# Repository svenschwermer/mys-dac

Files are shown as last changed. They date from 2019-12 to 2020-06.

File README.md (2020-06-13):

# Audio DAC around the MYS-6ULX-IOT

## UART
Connection diagram for JP1 with a FTDI TTL-232R cable:
1. TX – yellow
1. RX – orange
1. GND – black

## Host PC setup
NetworkManager:
```
nmcli con add \
    type ethernet
    ifname eno1 \
    con-name ethernet-static \
    ipv4.method manual \
    ipv4.addresses 192.168.100.1/24 \
    ipv6.method ignore
```

`/etc/dnsmasq.conf`
```
port=0
interface=eno1
dhcp-range=192.168.100.10,192.168.100.100,12h
enable-tftp
tftp-root=/srv/tftp
```

`/etc/nfs.conf`
```ini
[nfsd]
udp=y
vers2=y
```

`/etc/exports`
```
/srv/nfs/mys_rfs *(rw,no_root_squash,no_subtree_check)
```

## Unmute output
```sh
amixer sset 'Output Mixer HiFi' on
```

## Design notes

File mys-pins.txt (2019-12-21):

ECSPI1
MISO: CSI_DATA07 LCD_DATA23
MOSI: CSI_DATA06 LCD_DATA22
RDY: LCD_DATA12
SCLK: CSI_DATA04 LCD_DATA20
SS0: CSI_DATA05 LCD_DATA21
SS1: LCD_DATA05
SS2: LCD_DATA06
SS3: LCD_DATA07

ECSPI2
MISO: CSI_DATA03 UART5_RX_DATA
MOSI: CSI_DATA02 UART5_TX_DATA
RDY: LCD_ENABLE
SCLK: CSI_DATA00 UART4_TX_DATA
SS0: CSI_DATA01 UART4_RX_DATA
SS1: LCD_HSYNC
SS2: LCD_VSYNC
SS3: LCD_RESET

ECSPI3
MISO: NAND_CLE UART2_RTS_B
MOSI: NAND_CE1_B UART2_CTS_B
RDY: NAND_WP_B
SCLK: NAND_CE0_B UART2_RX_DATA
SS0: NAND_READY_B UART2_TX_DATA
SS1: NAND_ALE
SS2: NAND_RE_B
SS3: NAND_WE_B

ECSPI4
MISO: ENET2_TX_CLK NAND_DATA06
MOSI: ENET2_TX_EN NAND_DATA05
RDY: NAND_DATA00
SCLK: ENET2_TX_DATA1 NAND_DATA04
SS0: ENET2_RX_ER NAND_DATA07
SS1: NAND_DATA01
SS2: NAND_DATA02
SS3: NAND_DATA03

I2C1
SCL: CSI_PIXCLK GPIO1_IO02 UART4_TX_DATA
SDA: CSI_MCLK GPIO1_IO03 UART4_RX_DATA

I2C2
SCL: CSI_HSYNC GPIO1_IO00 UART5_TX_DATA
SDA: CSI_VSYNC GPIO1_IO01 UART5_RX_DATA

I2C3
SCL: ENET2_RX_DATA0 LCD_DATA01 UART1_TX_DATA
SDA: ENET2_RX_DATA1 LCD_DATA00 UART1_RX_DATA

I2C4
SCL: ENET2_RX_EN LCD_DATA03 UART2_TX_DATA
SDA: ENET2_TX_DATA0 LCD_DATA02 UART2_RX_DATA

SAI1:
MCLK: CSI_DATA01 LCD_DATA00
RX_BCLK: CSI_DATA03
RX_DATA: CSI_DATA06 LCD_DATA03
RX_SYNC: CSI_DATA02
TX_BCLK: CSI_DATA05 LCD_DATA02
TX_DATA: CSI_DATA07 LCD_DATA04
TX_SYNC: CSI_DATA04 LCD_DATA01

SAI2
MCLK: JTAG_TMS SD1_CLK
RX_BCLK: NAND_DATA06
RX_DATA: JTAG_TCK SD1_DATA2
RX_SYNC: SD1_CMD
TX_BCLK: JTAG_TDI SD1_DATA1
TX_DATA: JTAG_TRST_B SD1_DATA3
TX_SYNC: JTAG_TDO SD1_DATA0

SAI3
MCLK: LCD_CLK LCD_DATA09
RX_BCLK: LCD_DATA11
RX_DATA: LCD_DATA14
RX_SYNC: LCD_VSYNC LCD_DATA10
TX_BCLK: LCD_DATA13 LCD_HSYNC
TX_DATA: LCD_DATA15 LCD_RESET
TX_SYNC: LCD_DATA12 LCD_ENABLE

SPDIF
EXT_CLK: LCD_DATA07 NAND_DQS
IN: GPIO1_IO09 LCD_DATA08 SD1_CLK UART1_RX_DATA
LOCK: LCD_DATA06
OUT: GPIO1_IO08 JTAG_MOD LCD_DATA05 SD1_CMD UART1_TX_DATA
SR_CLK: LCD_DATA04

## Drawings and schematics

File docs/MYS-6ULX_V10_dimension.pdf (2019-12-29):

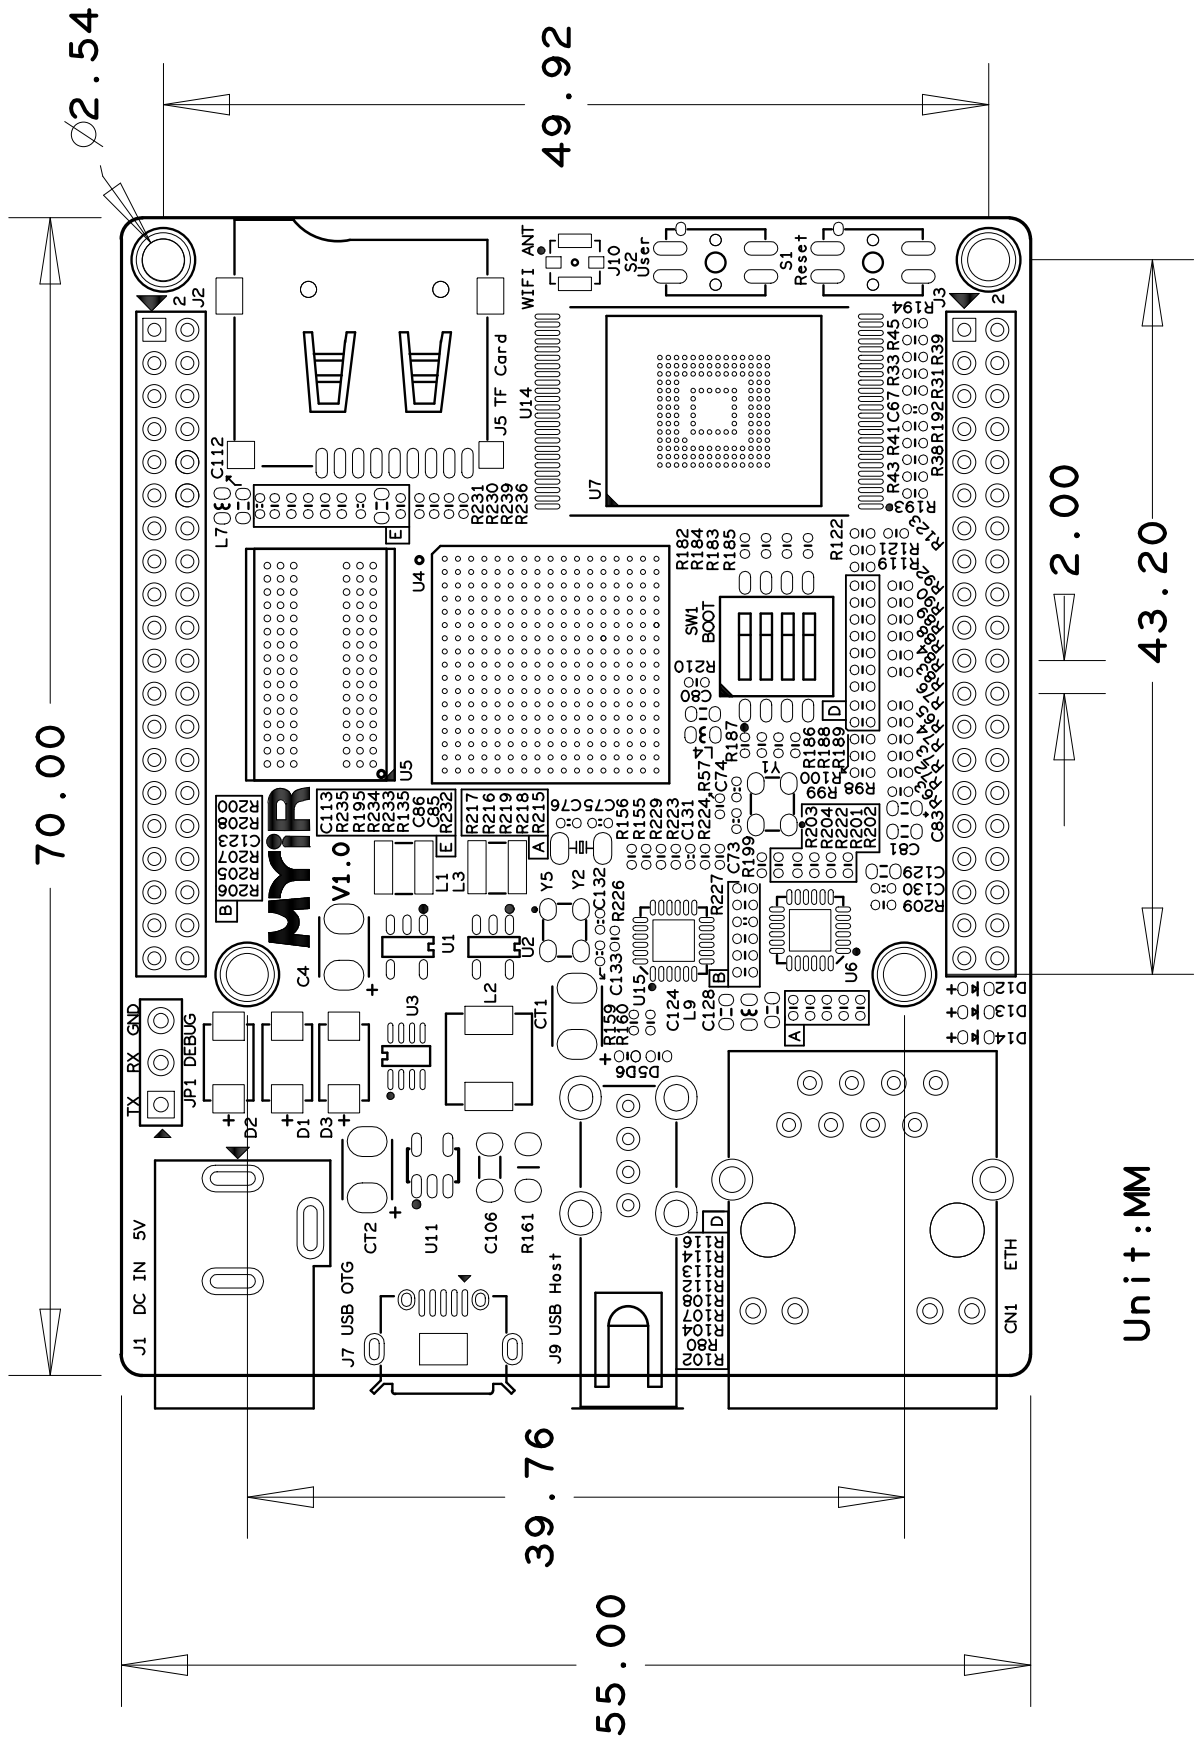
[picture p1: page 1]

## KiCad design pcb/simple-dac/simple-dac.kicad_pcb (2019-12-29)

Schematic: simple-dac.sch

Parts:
C1, C2, C3, C4, C12, C13, C14: 10µ; C_0805_2012Metric_Pad1.15x1.40mm_HandSolder
C5, C6, C9, C10, C11: 100n; C_0805_2012Metric_Pad1.15x1.40mm_HandSolder
C7, C8: 18p; C_0805_2012Metric_Pad1.15x1.40mm_HandSolder
C15, C16: 220µ; CP_Radial_D6.3mm_P2.50mm; Voltage 10V
H1, H2: MountingHole_Pad; KEYSTONE_7790
J1: Conn_02x07_Odd_Even; TE_MICRO-MATCH_FOB.14P
J2: AudioJack4; SJ-4351X-SMT
R1, R7, R8: 47k; R_0805_2012Metric_Pad1.15x1.40mm_HandSolder
R2, R5, R6: 0; R_0805_2012Metric_Pad1.15x1.40mm_HandSolder
R3: 680; R_0805_2012Metric_Pad1.15x1.40mm_HandSolder
R4: 40k; R_0805_2012Metric_Pad1.15x1.40mm_HandSolder
U1: WM8731; SSOP-28_5.3x10.2mm_P0.65mm
Y1: 11.2896MHz; Crystal_HC49-4H_Vertical

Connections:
+3V3: C2.1, C3.2, C5.1, C6.2, C9.1, C10.1, C12.1, C13.1, J1.2, U1.1, U1.8, U1.14, U1.27
BCLK: J1.8, U1.3
DIN: J1.5, U1.4
DOUT: J1.11, U1.6
GND: C1.1, C2.2, C3.1, C5.2, C6.1, C7.2, C8.2, C9.2, C10.2, C11.2, C12.2, C13.2, C14.2, J1.1, J2.S, R1.2, R7.2, R8.2, U1.11, U1.15, U1.21, U1.22, U1.28
LRCLK: J1.6, R2.2, U1.5
MCLK: J1.10, R6.2
MIC: C1.2, C4.1, J2.R2, R1.1, R3.1
unnamed: C4.2, R4.1
unnamed: C7.1, U1.26, Y1.1
unnamed: C8.1, R5.2, Y1.2
unnamed: C11.1, C14.1, U1.16
unnamed: C15.1, U1.9
unnamed: C15.2, J2.T, R8.1
unnamed: C16.1, U1.10
unnamed: C16.2, J2.R1, R7.1
unnamed: R2.1, U1.7
unnamed: R3.2, U1.17
unnamed: R4.2, U1.18
unnamed: R5.1, R6.1, U1.25
SCL: J1.4, U1.24
SDA: J1.3, U1.23

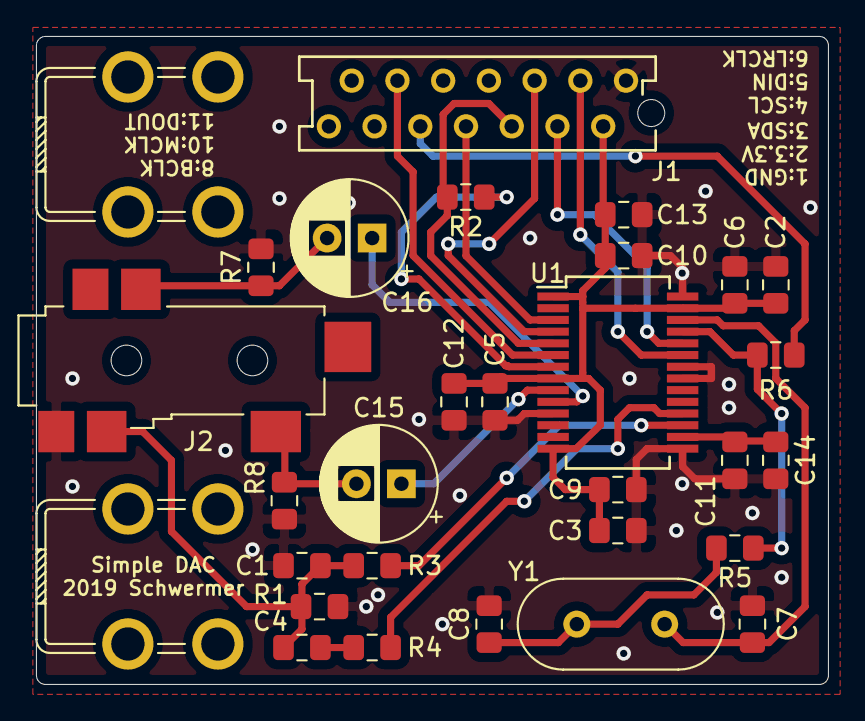
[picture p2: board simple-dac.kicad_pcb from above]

Board: 2 copper layers, 44.0 x 36.0 mm, 30 parts (0 on the bottom side), 22 nets.

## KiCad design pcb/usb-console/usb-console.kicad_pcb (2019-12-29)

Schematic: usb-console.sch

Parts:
C1: 10µ; C_0805_2012Metric_Pad1.15x1.40mm_HandSolder
C2, C3: 100n; C_0805_2012Metric_Pad1.15x1.40mm_HandSolder
D1: RED; LED_D3.0mm_Horizontal_O1.27mm_Z2.0mm
D2: GREEN; LED_D3.0mm_Horizontal_O3.81mm_Z6.0mm
H1, H2: MountingHole; KEYSTONE_7790
J1: USB_B_Mini; HIROSE_MX60-MB-5S8
J2: Conn_02x02_Odd_Even; TE_MICRO-MATCH_FOB.04P
R1, R2: R; R_0805_2012Metric_Pad1.15x1.40mm_HandSolder
U1: CH340E; MSOP-10_3x3mm_P0.5mm

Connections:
+5V: C1.1, C2.1, J1.1, J2.1, R2.2, U1.7
/D+: J1.3, U1.1
/D-: J1.2, U1.2
GND: C1.2, C2.2, C3.2, D1.1, D2.1, J1.5, J1.6, J2.4, U1.3
unnamed: C3.1, U1.10
unnamed: D1.2, R1.2
unnamed: D2.2, R2.1
unnamed: J2.2, U1.9
unnamed: J2.3, U1.8
unnamed: R1.1, U1.6

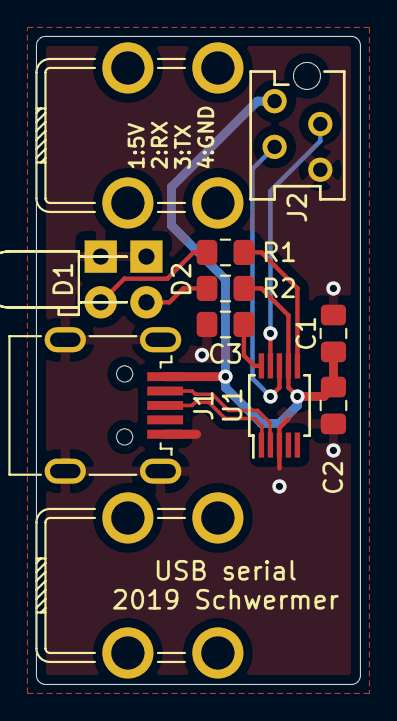
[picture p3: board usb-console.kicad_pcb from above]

Board: 2 copper layers, 18.0 x 36.0 mm, 12 parts (0 on the bottom side), 10 nets.

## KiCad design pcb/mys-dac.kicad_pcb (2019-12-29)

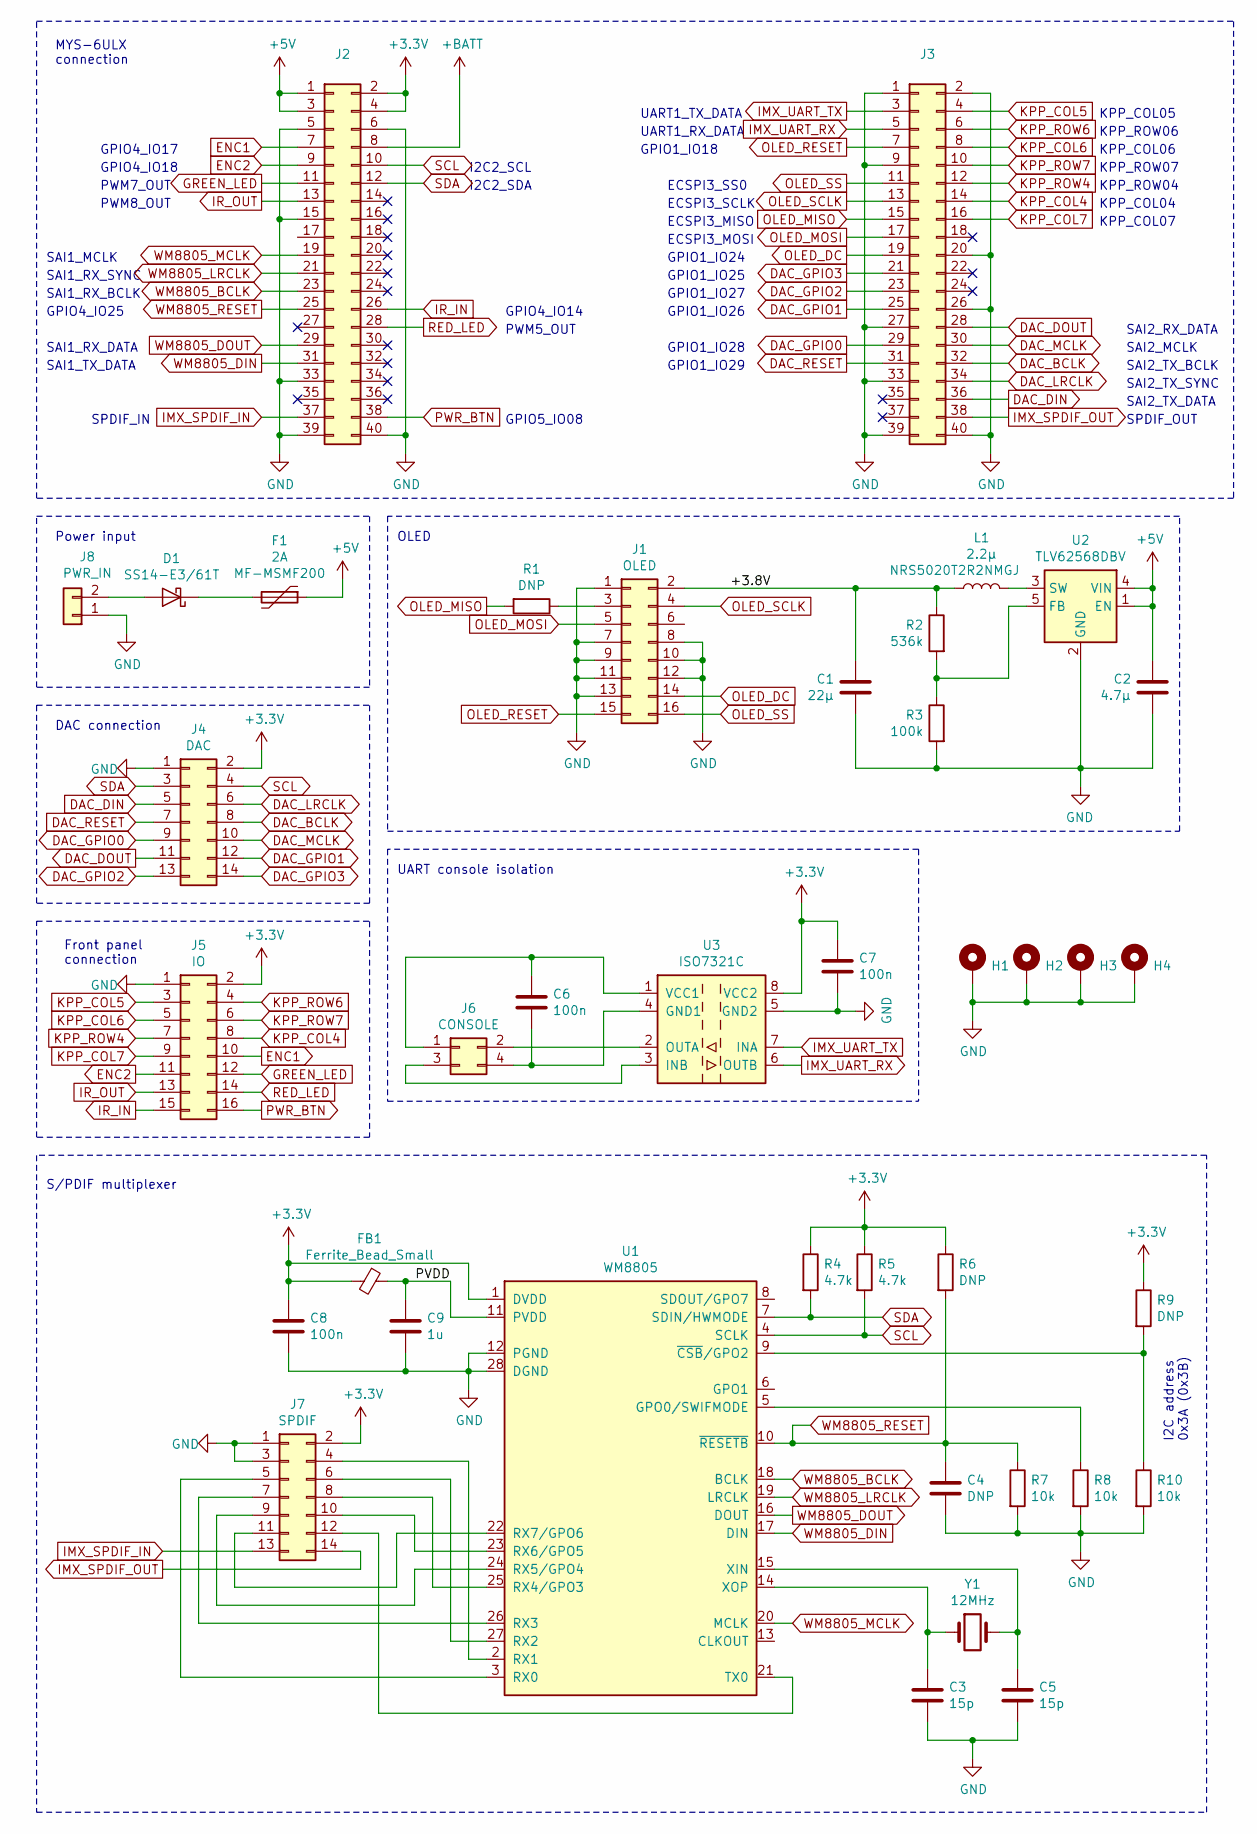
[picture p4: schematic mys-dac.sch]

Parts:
C1: 22µ; C_1206_3216Metric_Pad1.42x1.75mm_HandSolder
C2: 4.7µ; C_1206_3216Metric_Pad1.42x1.75mm_HandSolder
C3, C5: 15p; C_0805_2012Metric_Pad1.15x1.40mm_HandSolder
C4: C; C_0805_2012Metric_Pad1.15x1.40mm_HandSolder
C6, C7, C8: 100n; C_0805_2012Metric_Pad1.15x1.40mm_HandSolder
C9: 1u; C_0805_2012Metric_Pad1.15x1.40mm_HandSolder
D1: SS14-E3/61T; D_SMA_Handsoldering
F1: 2A; Fuse_1812_4532Metric_Pad1.30x3.40mm_HandSolder; Part MF-MSMF200
FB1: Ferrite_Bead_Small; L_0805_2012Metric_Pad1.15x1.40mm_HandSolder
H1, H2, H3, H4: MountingHole_Pad; MountingHole_2.5mm_Pad
J1: OLED; TE_MICRO-MATCH_FOB.16P
J2, J3: Conn_02x20_Odd_Even; PinSocket_2x20_P2.00mm_Vertical
J4: DAC; TE_MICRO-MATCH_FOB.14P
J5: IO; TE_MICRO-MATCH_FOB.16P
J6: CONSOLE; TE_MICRO-MATCH_FOB.04P
J7: SPDIF; TE_MICRO-MATCH_FOB.14P
J8: PWR_IN; JST_XH_B2B-XH-A_1x02_P2.50mm_Vertical
L1: 2.2µ; L_Taiyo-Yuden_NR-50xx_HandSoldering; Part NRS5020T2R2NMGJ
R1, R6, R9: R; R_0805_2012Metric_Pad1.15x1.40mm_HandSolder
R2: 536k; R_0805_2012Metric_Pad1.15x1.40mm_HandSolder
R3: 100k; R_0805_2012Metric_Pad1.15x1.40mm_HandSolder
R4, R5: 4.7k; R_0805_2012Metric_Pad1.15x1.40mm_HandSolder
R7, R8, R10: 10k; R_0805_2012Metric_Pad1.15x1.40mm_HandSolder
U1: WM8805; SSOP-28_5.3x10.2mm_P0.65mm
U2: TLV62568DBV; SOT-23-5
U3: ISO7321C; SOIC-8_3.9x4.9mm_P1.27mm
Y1: 12MHz; Crystal_HC49-4H_Vertical

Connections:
+3V3: C7.1, C8.1, FB1.2, J2.2, J2.4, J4.2, J5.2, J7.2, R4.1, R5.1, R6.1, R9.1, U1.1 (DVDD), U3.8 (VCC2)
+5V: C2.1, F1.1, J2.1, J2.3, U2.1 (EN), U2.4 (VIN)
+BATT: J2.8
/+3.8V: C1.1, J1.2, L1.2, R2.1
/PVDD: C9.1, FB1.1, U1.11 (PVDD)
DAC_BCLK: J3.32, J4.8
DAC_DIN: J3.36, J4.5
DAC_DOUT: J3.28, J4.11
DAC_GPIO0: J3.29, J4.9
DAC_GPIO1: J3.25, J4.12
DAC_GPIO2: J3.23, J4.13
DAC_GPIO3: J3.21, J4.14
DAC_LRCLK: J3.34, J4.6
DAC_MCLK: J3.30, J4.10
DAC_RESET: J3.31, J4.7
ENC1: J2.7, J5.10
ENC2: J2.9, J5.11
GND: C1.2, C2.2, C3.2, C4.2, C5.2, C7.2, C8.2, C9.2, H1.1, H2.1, H3.1, H4.1, J1.1, J1.7, J1.8, J1.9, J1.10, J1.11, J1.12, J1.13, J2.5, J2.6, J2.15, J2.33, J2.39, J2.40, J3.1, J3.2, J3.9, J3.20, J3.26, J3.27, J3.33, J3.39, J3.40, J4.1, J5.1, J7.1, J7.3, J8.1, R3.2, R7.2, R8.2, R10.2, U1.12 (PGND), U1.28 (DGND), U2.2 (GND), U3.5 (GND2)
GREEN_LED: J2.11, J5.12
IMX_SPDIF_IN: J2.37, J7.13
IMX_SPDIF_OUT: J3.38, J7.14
IMX_UART_RX: J3.5, U3.6 (OUTB)
IMX_UART_TX: J3.3, U3.7 (INA)
IR_IN: J2.26, J5.15
IR_OUT: J2.13, J5.13
KPP_COL4: J3.14, J5.8
KPP_COL5: J3.4, J5.3
KPP_COL6: J3.8, J5.5
KPP_COL7: J3.16, J5.9
KPP_ROW4: J3.12, J5.7
KPP_ROW6: J3.6, J5.4
KPP_ROW7: J3.10, J5.6
unnamed: C3.1, U1.14 (XOP), Y1.1
unnamed: C5.1, U1.15 (XIN), Y1.2
unnamed: C6.1, J6.1, U3.1 (VCC1)
unnamed: C6.2, J6.4, U3.4 (GND1)
unnamed: D1.1 (K), F1.2
unnamed: D1.2 (A), J8.2
unnamed: J1.3, R1.1
unnamed: J6.2, U3.2 (OUTA)
unnamed: J6.3, U3.3 (INB)
unnamed: J7.4, U1.2 (RX1)
unnamed: J7.5, U1.3 (RX0)
unnamed: J7.6, U1.27 (RX2)
unnamed: J7.7, U1.26 (RX3)
unnamed: J7.8, U1.25 (RX4/GPO3)
unnamed: J7.9, U1.24 (RX5/GPO4)
unnamed: J7.10, U1.23 (RX6/GPO5)
unnamed: J7.11, U1.22 (RX7/GPO6)
unnamed: J7.12, U1.21 (TX0)
unnamed: L1.1, U2.3 (SW)
unnamed: R2.2, R3.1, U2.5 (FB)
unnamed: R8.1, U1.5 (GPO0/SWIFMODE)
unnamed: R9.2, R10.1, U1.9 (~CSB~/GPO2)
OLED_DC: J1.14, J3.19
OLED_MISO: J3.15, R1.2
OLED_MOSI: J1.5, J3.17
OLED_RESET: J1.15, J3.7
OLED_SCLK: J1.4, J3.13
OLED_SS: J1.16, J3.11
PWR_BTN: J2.38, J5.16
RED_LED: J2.28, J5.14
SCL: J2.10, J4.4, R5.2, U1.4 (SCLK)
SDA: J2.12, J4.3, R4.2, U1.7 (SDIN/HWMODE)
WM8805_BCLK: J2.23, U1.18 (BCLK)
WM8805_DIN: J2.31, U1.17 (DIN)
WM8805_DOUT: J2.29, U1.16 (DOUT)
WM8805_LRCLK: J2.21, U1.19 (LRCLK)
WM8805_MCLK: J2.19, U1.20 (MCLK)
WM8805_RESET: C4.1, J2.25, R6.2, R7.1, U1.10 (~RESETB)

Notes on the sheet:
I2C address 0x3A (0x3B)
UART console isolation
OLED
MYS-6ULX connection
PWM7_OUT
SAI1_MCLK
GPIO4_IO18
GPIO4_IO17
PWM8_OUT
SAI1_RX_SYNC
SAI1_RX_BCLK
GPIO4_IO25
SAI1_RX_DATA
SAI1_TX_DATA
SPDIF_IN
I2C2_SCL
GPIO4_IO14
PWM5_OUT
GPIO5_IO08
UART1_TX_DATA
UART1_RX_DATA
GPIO1_IO18
ECSPI3_SS0
ECSPI3_SCLK
ECSPI3_MISO
ECSPI3_MOSI
GPIO1_IO24
GPIO1_IO25
GPIO1_IO27
GPIO1_IO26
GPIO1_IO28
GPIO1_IO29
KPP_COL05
KPP_ROW06
KPP_COL06
KPP_ROW07
KPP_ROW04
KPP_COL04
KPP_COL07
SAI2_RX_DATA

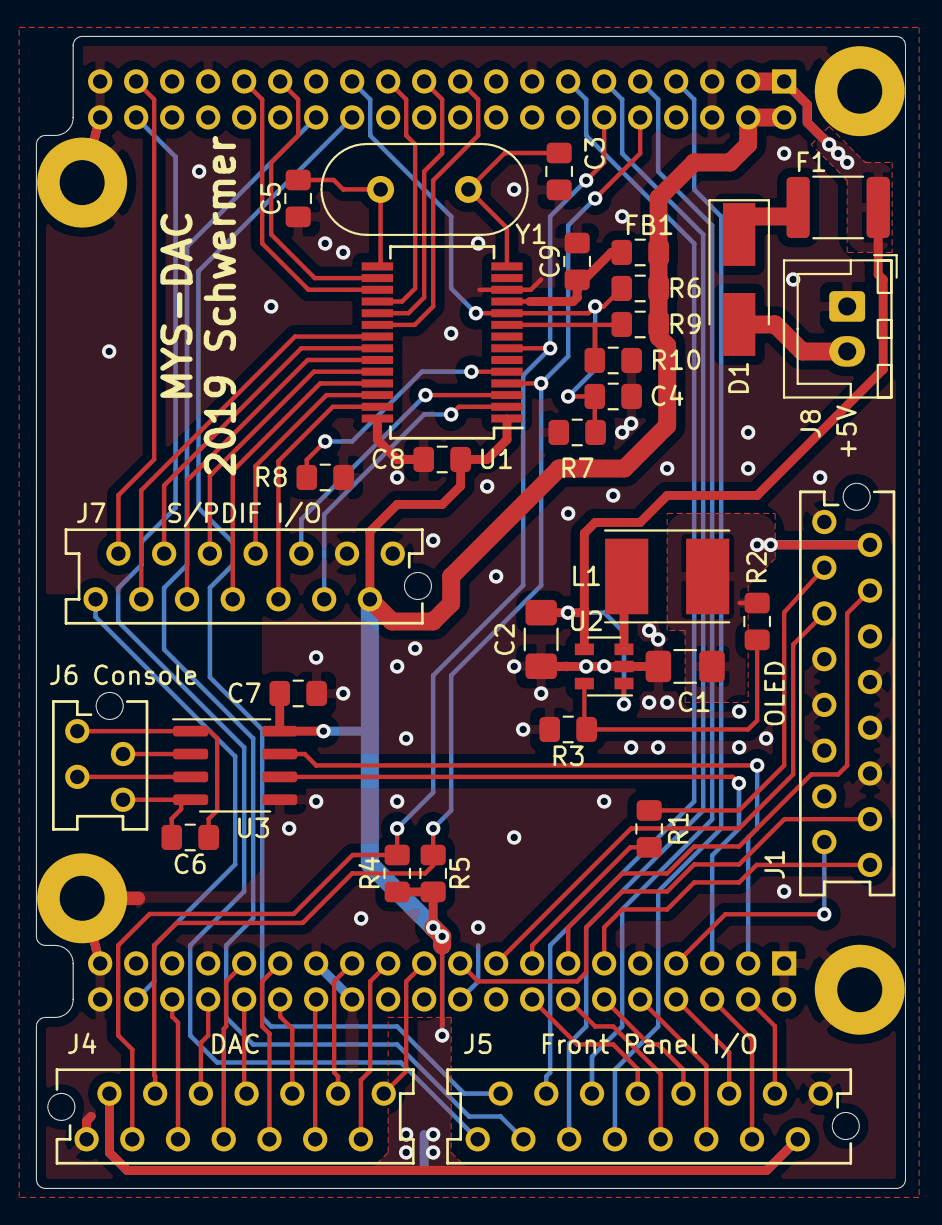
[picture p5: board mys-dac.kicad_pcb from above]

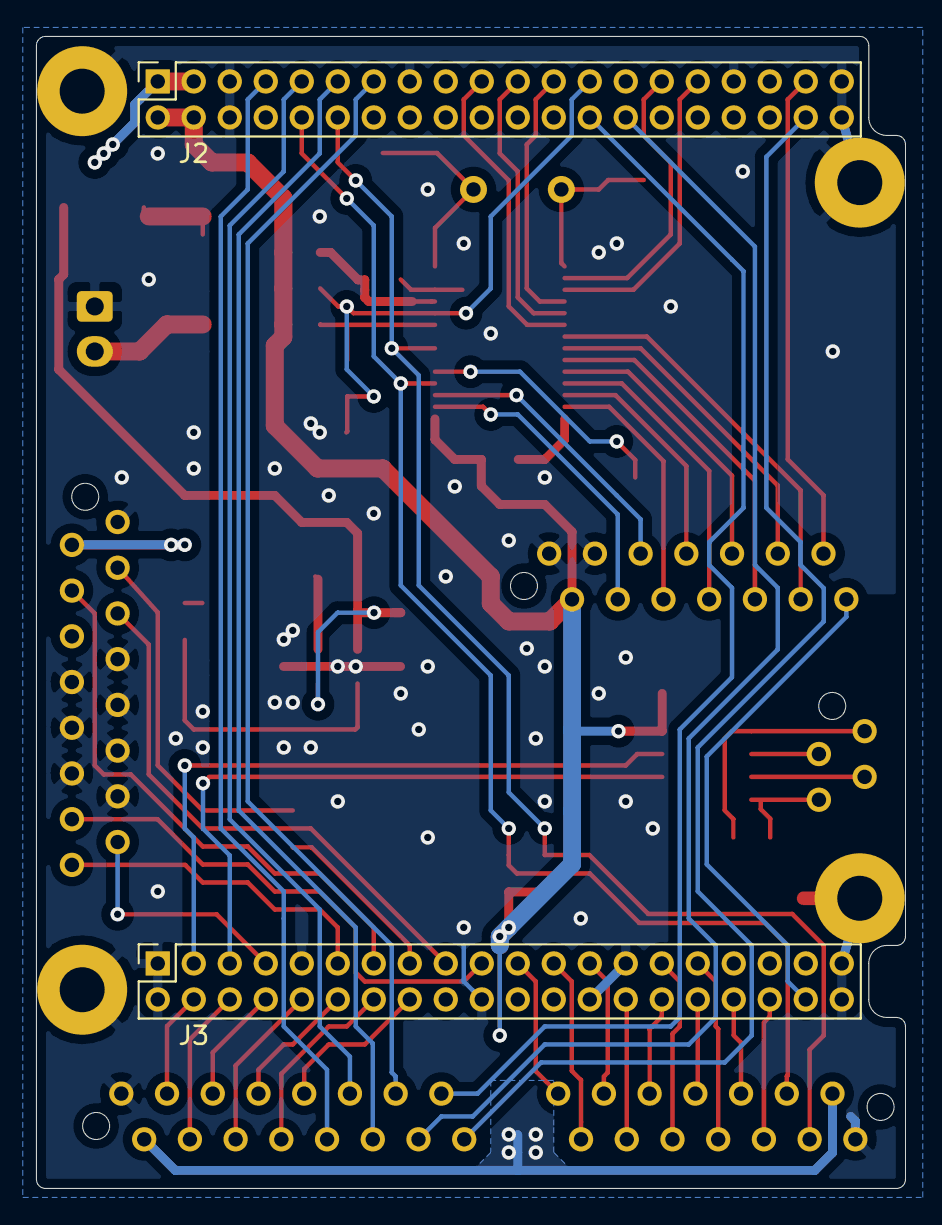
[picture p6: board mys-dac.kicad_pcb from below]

Board: 2 copper layers, 48.3 x 64.0 mm, 39 parts (2 on the bottom side), 69 nets.

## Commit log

2019-12-23 pcb: Initial state (J2/J3 mixed up)
    [mys-dac.kicad_pcb, mys-dac.sch]
2019-12-26 Almost completely routed
    [mys-dac.kicad_pcb, mys-dac.sch]
2019-12-26 Routing complete
    [mys-dac.kicad_pcb]
2019-12-28 Done routing
    [mys-dac.kicad_pcb, mys-dac.sch, simple-dac.kicad_pcb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]
2019-12-29 PCBs sent to fab
    [mys-dac.kicad_pcb, simple-dac.kicad_pcb, usb-console.kicad_pcb]
2020-02-01 pcb: Update usb-console resistor values
    [usb-console.sch]
2020-06-13 Fixes for building on Arch
    https://svenschwermer.de/2020/06/12/building-yocto-on-up-to-date-arch-linux.html
2020-06-13 Audio playback via WM8731 functional
    [mys-dac.sch, simple-dac.sch]
2020-06-13 Add WiFi driver
    [rtl8188eu.cfg]
